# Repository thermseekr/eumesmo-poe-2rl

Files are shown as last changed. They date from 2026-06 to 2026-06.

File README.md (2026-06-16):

# eumesmo-poe-2rl
PoE powered ESP32 based board featuring two SPST NO relays. Ideal for access control, doors, isolated zones or for installing anywhere you need to click dry contacts near some equipment or appliance.

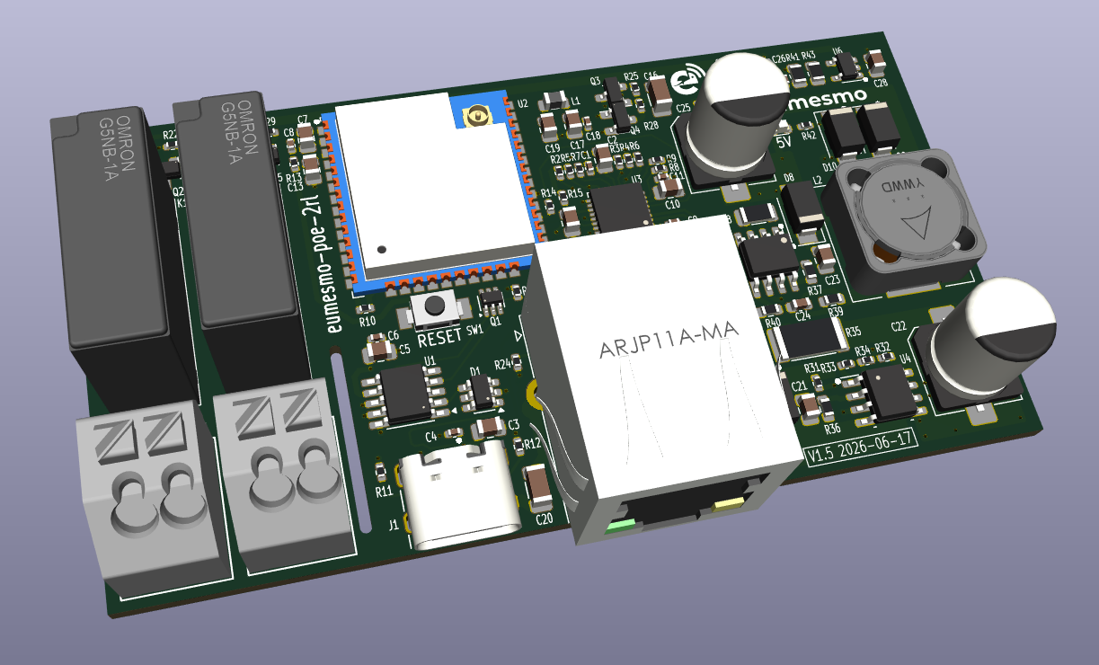
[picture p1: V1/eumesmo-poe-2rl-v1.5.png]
eumesmo-poe-2rl


## VERSION HISTORY

V1.5 - 2026/06/13 - Repository renamed from ESP-POE-2RL to eumesmo-poe-2rl to align the design with the **eumesmo** line of building automation products.

V1.4 - 2026/06/10 - Terminal blocks replaced for 3.5mm pitch. Deleted temperature sensor, board decreased 8mm in length. LAN8710A rotated for shorter traces. Pull-up resistor for MDIO adjusted from 2.2k to 1.5k as suggested in the datasheet. Bulk and decoupling capacitor sizes and types adjusted for better performance.

V1.3 - 2025/06/29 - Layers reordered and board fully rerouted for better signal integrity.

V1.2 - 2024/12/07 - Connectors adjusted for best fitting the case.

V1.1 - 2024/11/29 - Initial release.

## LICENSE

This project is licensed under the [Creative Commons BY-NC 4.0 License](https://creativecommons.org/licenses/by-nc/4.0/).
Commercial use is not permitted without prior written consent. See the [LICENSE.txt](LICENSE.txt) file for details.

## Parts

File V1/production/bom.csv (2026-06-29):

Designator | Footprint | Quantity | Value | LCSC Part #
C1, C12, C15, C18, C4, C6, C8, C9 | 0402 | 8 | 100nF/50V | C307331
C10, C13, C3 | 0805 | 3 | 1uF/50V | C28323
C11 | 0402 | 1 | 470pF/50V | C1537
C14, C17, C19, C2, C28, C5, C7 | 0805 | 7 | 10uF/25V | C15850
C16, C27 | 1206 | 2 | 22uF/10V | C5672
C20 | 1206 | 1 | 1nF/2kV | C161353
C21, C23 | 0805 | 2 | 100nF/100V | C28233
C22 | CP_Elec_8x10.5 | 1 | 22uF/100V | C178570
C24 | 0603 | 1 | 12pF/50V | C38523
C25 | CP_Elec_8x10.5 | 1 | 470uF/16V | C96179
C26 | 0402 | 1 | 22pF/50V | C1555
D1 | SOT-23-6 | 1 | USBLC6-2SC6 | C7519
D10, D12, D8 | 0603 | 3 | WHITE | C2290
D11, D9 | D_SOD-123 | 2 | 1N4148 | C81598
D2 | SOT-23-5 | 1 | ESDS314DBV | C1847859
D3 | 0603 | 1 | WHITE/0603 | C2290
D4 | D_SMA | 1 | SMAJ58A | C132936
D5 | D_SMA | 1 | SS510 | C65010
D6, D7 | D_SMA | 2 | SS34 | C8678
J1 | USB_C_Receptacle_GCT_USB4105-xx-A_16P_TopMnt_Horizontal | 1 | USB_C_Receptacle_USB2.0 | C2765186
J2 | RJ45_HanRun_HY931147C | 1 | RJ45 JACK | C91754
J3, J4 | TerminalBlock_Wago_250-202_1x02_P3.5mm_45Degree | 2 | 250-202 | C2765061
K1, K2 | Relay_SPST_Omron_G5NB-1A | 2 | G5NB-1A-E-DC5 | C48746
L1 | 0805 | 1 | 2A/600R | C139168
L2 | L_12x12mm_H6mm | 1 | 33uH/2,1A | C169386
L3 | L_3x3mm_H1.5mm | 1 | 2,2uH/1,5A | C370424
Q1 | SOT-363_SC-70-6 | 1 | UMH3N | C62892
Q2 | SOT-23 | 1 | WPM2015-3/TR | C558305
Q3 | SOT-23 | 1 | LMUN2211LT1G | C150229
Q4, Q5 | SOT-23 | 2 | MMBT2222A | C8512
R1, R10, R13, R16, R22, R29, R41, R44 | 0402 | 8 | 10k | C25744
R11, R12 | 0402 | 2 | 5,1k | C105872
R14 | 0402 | 1 | 33R | C25105
R15, R37 | 0402 | 2 | 300R | C25102
R17, R19, R20, R21 | 0402 | 4 | 49,9R | C25120
R18 | 0402 | 1 | 12,1k | C25852
R2 | 0402 | 1 | 1.5k | C25867
R23, R25 | 0402 | 2 | 330R | C25104
R24, R40, R43 | 0402 | 3 | 1k | C11702
R26 | 0402 | 1 | 30,1k | C138009
R27 | 0402 | 1 | 130k | C93946
R28 | 0402 | 1 | 180k | C138046
R3, R4, R5, R6, R7, R8, R9 | 0402 | 7 | 2.2k | C25879
R30 | 2512 | 1 | 4,7k/1W | C878291
R31 | 0603 | 1 | 4,42k/100mW | C482858
R32 | 0603 | 1 | 5,1R/100mW | C25197
R33 | 1206 | 1 | 30mR/250mW | C473665
R34 | 0603 | 1 | 300k/100mW | C23024
R35 | 0603 | 1 | 52,3k/100mW | C185323
R36 | 0805 | 1 | 100k/0,125W | C149504
R38 | 0805 | 1 | 22,1k/0,125W | C17552
R39, R42 | 0402 | 2 | 680R | C25130
SW1 | SW_SPST_Xunpu_TS1088AR02016 | 1 | RESET | C720477
U1 | SSOP-10-1EP_3.9x4.9mm_P1mm_EP2.1x3.3mm | 1 | CH340K | C968586
U2 | ESP32-WROOM-32U | 1 | ESP32-WROOM-32UE-N16 | C701346
U3 | QFN-32-1EP_5x5mm_P0.5mm_EP3.3x3.3mm_ThermalVias | 1 | LAN8710A | C46185
U4 | SOIC-8-1EP_3.9x4.9mm_P1.27mm_EP2.95x4.9mm_Mask2.71x3.4mm_ThermalVias | 1 | TPS2376DDAR-H | C544899
U5 | SOIC-8-1EP_3.9x4.9mm_P1.27mm_EP2.41x3.81mm_ThermalVias | 1 | TX4138 | C329267
U6 | SOT-23-5_Shorter_Pins | 1 | SY8089A1AAC | C479074

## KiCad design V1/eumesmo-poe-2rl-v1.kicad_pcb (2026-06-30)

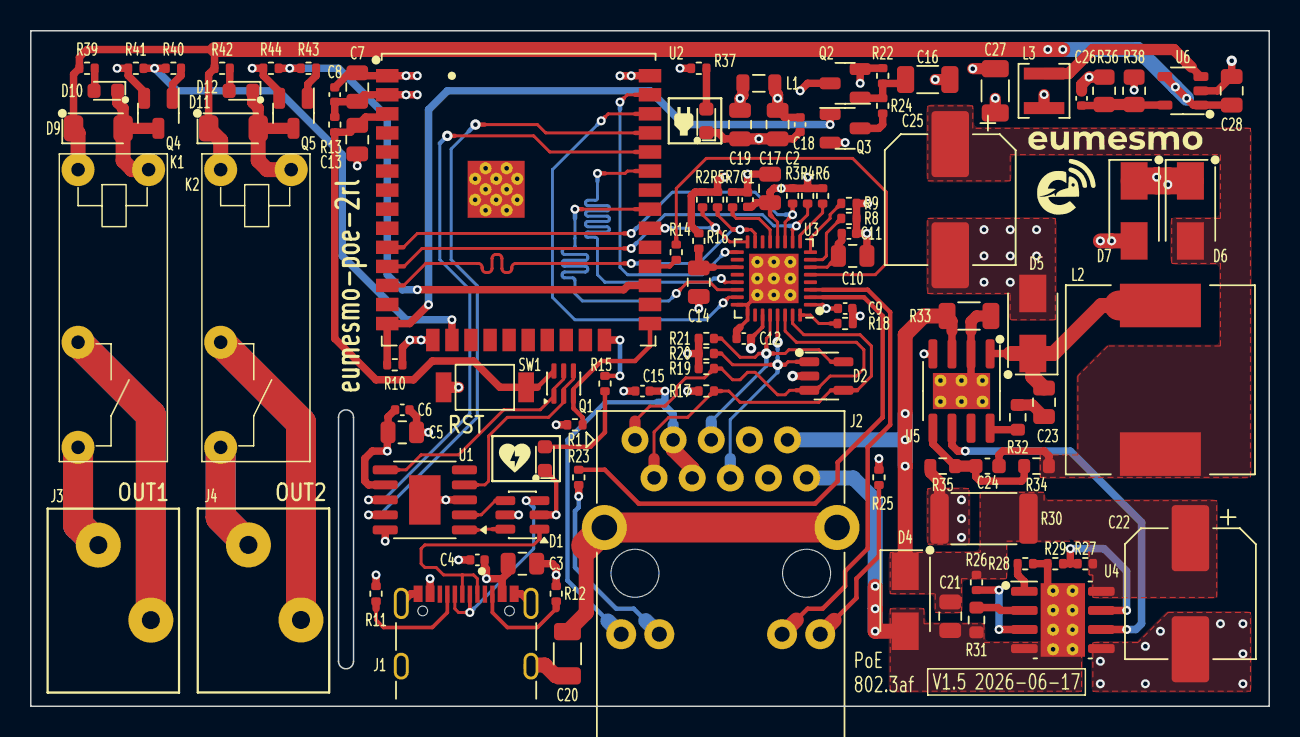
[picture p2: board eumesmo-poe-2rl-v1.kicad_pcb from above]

Board: 4 copper layers, 82.5 x 45.0 mm, 105 parts (0 on the bottom side), 77 nets.

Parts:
C1, C4, C6, C8, C9, C12, C15, C18: 100nF/50V; C_0402_1005Metric
C2, C5, C7, C14, C17, C19, C28: 10uF/25V; C_0805_2012Metric
C3, C10, C13: 1uF/50V; C_0805_2012Metric
C11: 470pF/50V; C_0402_1005Metric
C16, C27: 22uF/10V; C_1206_3216Metric
C20: 1nF/2kV; C_1206_3216Metric
C21, C23: 100nF/100V; C_0805_2012Metric
C22: 22uF/100V; CP_Elec_8x10.5
C24: 12pF/50V; C_0603_1608Metric
C25: 470uF/16V; CP_Elec_8x10.5
C26: 22pF/50V; C_0402_1005Metric
D1: USBLC6-2SC6; SOT-23-6
D2: ESDS314DBV; SOT-23-5
D3: WHITE/0603; LED_0603_1608Metric
D4: SMAJ58A; D_SMA
D5: SS510; D_SMA
D6, D7: SS34; D_SMA
D8, D10, D12: WHITE; LED_0603_1608Metric
D9, D11: 1N4148; D_SOD-123
J1: USB_C_Receptacle_USB2.0; USB_C_Receptacle_GCT_USB4105-xx-A_16P_TopMnt_Horizontal
J2: RJ45 JACK; RJ45_HanRun_HY931147C
J3, J4: 250-202; TerminalBlock_Wago_250-202_1x02_P3.5mm_45Degree
K1, K2: G5NB-1A-E-DC5; Relay_SPST_Omron_G5NB-1A
L1: 2A/600R; L_0805_2012Metric
L2: 33uH/2,1A; L_12x12mm_H6mm
L3: 2,2uH/1,5A; L_3x3mm_H1.5mm
Q1: UMH3N; SOT-363_SC-70-6
Q2: WPM2015-3/TR; SOT-23
Q3: LMUN2211LT1G; SOT-23
Q4, Q5: MMBT2222A; SOT-23
R1, R10, R13, R16, R22, R29, R41, R44: 10k; R_0402_1005Metric
R2: 1.5k; R_0402_1005Metric
R3, R4, R5, R6, R7, R8, R9: 2.2k; R_0402_1005Metric
R11, R12: 5,1k; R_0402_1005Metric
R14: 33R; R_0402_1005Metric
R15, R37: 300R; R_0402_1005Metric
R17, R19, R20, R21: 49,9R; R_0402_1005Metric
R18: 12,1k; R_0402_1005Metric
R23, R25: 330R; R_0402_1005Metric
R24, R40, R43: 1k; R_0402_1005Metric
R26: 30,1k; R_0402_1005Metric
R27: 130k; R_0402_1005Metric
R28: 180k; R_0402_1005Metric
R30: 4,7k/1W; R_2512_6332Metric
R31: 4,42k/100mW; R_0603_1608Metric
R32: 5,1R/100mW; R_0603_1608Metric
R33: 30mR/250mW; R_1206_3216Metric
R34: 300k/100mW; R_0603_1608Metric
R35: 52,3k/100mW; R_0603_1608Metric
R36: 100k/0,125W; R_0805_2012Metric
R38: 22,1k/0,125W; R_0805_2012Metric
R39, R42: 680R; R_0402_1005Metric
SW1: RESET; SW_SPST_Xunpu_TS1088AR02016
U1: CH340K; SSOP-10-1EP_3.9x4.9mm_P1mm_EP2.1x3.3mm
U2: ESP32-WROOM-32UE-N16; ESP32-WROOM-32U
U3: LAN8710A; QFN-32-1EP_5x5mm_P0.5mm_EP3.3x3.3mm_ThermalVias
U4: TPS2376DDAR-H; SOIC-8-1EP_3.9x4.9mm_P1.27mm_EP2.95x4.9mm_Mask2.71x3.4mm_Th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
U5: TX4138; SOIC-8-1EP_3.9x4.9mm_P1.27mm_EP2.41x3.81mm_ThermalVias
U6: SY8089A1AAC; SOT-23-5_Shorter_Pins

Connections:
5VPOE: C24.1, C25.1, D6.2 (A), L2.2, R34.1
5VUSB: C3.1, C4.1, D1.5 (VBUS), D7.2 (A), J1.A4 (VBUS), J1.A9 (VBUS), J1.B4 (VBUS), J1.B9 (VBUS)
+3V3: C5.1, C6.1, C7.1, C8.1, C16.1, C26.1, C27.1, L3.2, Q2.2 (S), R1.1, R13.1, R22.1, R36.1, R37.1, U1.7 (VCC), U1.10 (V3), U2.2 (VDD)
+3V3A: C9.1, C12.1, C15.1, C19.1, J2.3 (CT), J2.4 (CT), J2.11 (LLED+), L1.2, R17.2, R19.2, R20.2, R21.2, U3.1 (VDD2A), U3.27 (VDD1A)
+3V3LAN: C1.1, C2.1, C17.1, C18.1, L1.1, Q2.3 (D), R2.1, R3.1, R4.1, R5.1, R6.1, R16.2, U3.12 (VDDIO)
+5V: C28.1, D6.1 (K), D7.1 (K), D9.1 (K), D11.1 (K), K1.1, K2.1, R39.1, R42.1, U6.1 (EN), U6.4 (IN)
/CPULED: D3.2 (A), R15.2
/CPUOK: R15.1, U2.24 (IO2)
/EMACCLK: R14.2, U3.5 (XTAL1/CLKIN)
/EMACMDC: U2.37 (IO23), U3.17 (MDC)
/EMACMDIO: R2.2, U2.30 (IO18), U3.16 (MDIO)
/EMACRX: R5.2, U2.12 (IO27), U3.15 (COL/CRS_DV/~MODE2)
/EMACRXCLK: R8.2, U3.7 (RXCLK/~PHYAD1)
/EMACRXD0: R3.2, U2.10 (IO25), U3.11 (RXD0/~MODE0)
/EMACRXD1: R4.2, U2.11 (IO26), U3.10 (RXD1/~MODE1)
/EMACRXD2: R6.2, U3.9 (RXD2/~RMIISEL)
/EMACRXD3: R9.2, U3.8 (RXD3/~PHYAD2)
/EMACRXD4: R7.2, U3.13 (RXER/RXD4/~PHYAD0)
/EMACTXD0: U2.31 (IO19), U3.22 (TXD0)
/EMACTXD1: U2.36 (IO22), U3.23 (TXD1)
/EMACTXEN: U2.33 (IO21), U3.21 (TXEN)
/ESPCLK: R14.1, U2.28 (IO17)
/ESPEN: C13.1, Q1.6 (C1), R13.2, SW1.2, U2.3 (EN)
/ESPPROG: Q1.3 (C2), R1.2, U2.25 (IO0)
/ETHLEDGA: J2.13 (RLED+), U3.3 (LED1/~REGOFF)
/ETHLEDGK: J2.14 (RLED-), R25.2
/ETHLEDY: R23.2, U3.2 (LED2/~INTSEL)
/ETHLEDYK: J2.12 (LLED-), R23.1
/ETHRXD+: D2.4 (I/03), J2.2 (RD+), R17.1, U3.31 (RXP)
/ETHRXD-: D2.3 (I/02), J2.1 (RD-), R19.1, U3.30 (RXN)
/ETHSH: C20.1, J2.15 (SHIELD)
/ETHTXD+: D2.1 (I/01), J2.6 (TD+), R20.1, U3.29 (TXP)
/ETHTXD-: D2.5 (I/04), J2.5 (TD-), R21.1, U3.28 (TXN)
/PHYNRST: C14.2, R16.1, U3.19 (~RST)
/PHYPWRBJT: Q3.3 (C), R24.2
/PHYPWRFET: C16.2, Q2.1 (G), R22.2, R24.1
/POWER/3V3LED: D8.2 (A), R37.2
/POWER/3V3REF: C26.2, R36.2, R38.1, U6.5 (FB)
/POWER/3V3SW: L3.1, U6.3 (LX)
/POWER/5VBS: C23.1, R32.1
/POWER/5VREF: C24.2, R34.2, R35.1, U5.5 (FB)
/POWER/5VSW: C23.2, D5.1 (K), L2.1, U5.1 (SW)
/POWER/BS: R32.2, U5.8 (BS)
/POWER/ILIM: R33.2, U5.2 (ILIM), U5.9 (ILIM)
/POWER/RCLASS: R31.1, U4.2 (CLASS)
/POWER/RDET: R26.2, U4.3 (DET)
/POWER/RILIM: R28.1, U4.1 (ILIM)
/POWER/VTAP: R27.2, R29.1, U4.7 (UVLO)
/RBIAS: R18.1, U3.32 (RBIAS)
/RELAY OUTPUTS/OUT1BJT: Q4.1 (B), R40.1
/RELAY OUTPUTS/OUT1CMD: D9.2 (A), D10.1 (K), K1.4, Q4.3 (C)
/RELAY OUTPUTS/OUT1LD: J3.1, K1.3
/RELAY OUTPUTS/OUT1LN: J3.2, K1.2
/RELAY OUTPUTS/OUT1ON: D10.2 (A), R39.2
/RELAY OUTPUTS/OUT2BJT: Q5.1 (B), R43.1
/RELAY OUTPUTS/OUT2CMD: D11.2 (A), D12.1 (K), K2.4, Q5.3 (C)
/RELAY OUTPUTS/OUT2LD: J4.1, K2.3
/RELAY OUTPUTS/OUT2LN: J4.2, K2.2
/RELAY OUTPUTS/OUT2ON: D12.2 (A), R42.2
/UARTNDTR: Q1.2 (B1), Q1.4 (E2), U1.4 (~DTR)
/UARTNRTS: Q1.1 (E1), Q1.5 (B2), U1.6 (~RTS)
/UARTRXD: U1.9 (RXD), U2.35 (TXD0/IO1)
/UARTTXD: U1.8 (TXD), U2.34 (RXD0/IO3)
/USBCC1: J1.A5 (CC1), R11.1
/USBCC2: J1.B5 (CC2), R12.1
/USBCD+: D1.1 (I/O1), J1.A6 (D+), J1.B6 (D+)
/USBCD-: D1.3 (I/O2), J1.A7 (D-), J1.B7 (D-)
/USBD+: D1.6 (I/O1), U1.1 (UD+)
/USBD-: D1.4 (I/O2), U1.2 (UD-)
/VDDCR: C10.1, C11.1, U3.6 (VDDCR)
GND: C1.2, C2.2, C3.2, C4.2, C5.2, C6.2, C7.2, C8.2, C9.2, C10.2, C11.2, C12.2, C13.2, C14.1, C15.2, C17.2, C18.2, C19.2, C20.2, C22.2, C25.2, C27.2, C28.2, D1.2 (GND), D2.2 (GND), D3.1 (K), D5.2 (A), D8.1 (K), J1.A1 (GND), J1.A12 (GND), J1.B1 (GND), J1.B12 (GND), J1.S1 (SHIELD), Q3.2 (E), Q4.2 (E), Q5.2 (E), R7.1, R8.1, R9.1, R10.1, R11.2, R12.2, R18.2, R25.1, R30.2, R35.2, R38.2, R41.2, R44.2, SW1.1, U1.3 (GND), U1.11 (GND), U2.1 (GND), U2.15 (GND), U2.38 (GND), U2.39 (GND), U3.24 (TXD2), U3.25 (TXD3), U3.33 (VSS), U4.5 (RTN), U5.4 (GND), U6.2 (GND)
OUT1: R40.2, R41.1, U2.16 (IO13)
OUT2: R43.2, R44.1, U2.27 (IO16)
PG: U4.6 (PG), U5.6 (EN)
PHYPWR: Q3.1 (B), R10.2, U2.14 (IO12)
POE+: C21.1, C22.1, D4.1 (K), J2.9 (V+), R26.1, R27.1, R30.1, R33.1, U4.8 (VDD), U5.3 (VIN)
POE-: C21.2, D4.2 (A), J2.10 (V-), R28.2, R29.2, R31.2, U4.4 (VSS), U4.9 (PPAD)

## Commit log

2026-03-10 Update power rail names
    [esp-poe-2rl-V1.kicad_pcb, esp-poe-2rl-V1.kicad_sch]
2026-06-03 addressing the PHY power rails
    [esp-poe-2rl-V1-power.kicad_sch, esp-poe-2rl-V1.kicad_pcb, esp-poe-2rl-V1.kicad_sch]
2026-06-08 Replaced terminal blocks
    [esp-poe-2rl-V1-power.kicad_sch, esp-poe-2rl-V1.kicad_pcb, esp-poe-2rl-V1.kicad_sch]
2026-06-09 Update resistance value for pull-ups.
    [bom.csv, esp-poe-2rl-V1.kicad_pcb, esp-poe-2rl-V1.kicad_sch]
2026-06-09 Revising before manufacture
    [esp-poe-2rl-V1-power.kicad_sch, esp-poe-2rl-V1.kicad_pcb, esp-poe-2rl-V1.kicad_sch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]
2026-06-12 Streamlining version numbers.
    [esp-poe-2rl-V1.kicad_pcb]
2026-06-13 Renamed all files to eumesmo branding
    [eumesmo-poe-2rl-v1-outputs.kicad_sch, eumesmo-poe-2rl-v1-power.kicad_sch, eumesmo-poe-2rl-v1.kicad_pcb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]
2026-06-16 Rerouted ETH TX/RX pairs.
    [eumesmo-poe-2rl-v1.kicad_pcb]
2026-06-16 Adjusted LED trace width.
    [eumesmo-poe-2rl-v1.kicad_pcb, positions.csv]
2026-06-16 Rerouted TX/RX pairs between magjack and PHY.
    [eumesmo-poe-2rl-v1.kicad_pcb]
2026-06-17 Widened tracks at pads and vias
    [eumesmo-poe-2rl-v1.kicad_pcb]
2026-06-17 Release V1.5.0
    [eumesmo-poe-2rl-v1-outputs.kicad_sch, eumesmo-poe-2rl-v1-power.kicad_sch, eumesmo-poe-2rl-v1.kicad_pcb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]
2026-06-29 Added CPU health LED
    [bom.csv, designators.csv, eumesmo-poe-2rl-v1-outputs.kicad_sch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]
